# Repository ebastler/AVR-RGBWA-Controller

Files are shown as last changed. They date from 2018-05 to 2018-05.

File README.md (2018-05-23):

## AVR RGBWA Controller
### Overview
This project was born as an ambient light for a living room. I wanted five controllable LED channels and compatibility with 12 V or 24 V LED stripes and an easy to use interface with a single rotary encoder (and it's push button). As a controller I chose an "Arduino pro Micro" from China, because I wanted to be able to add USB support later on and the arduino features an ATmega32U4 with all necessary external components. It was, however, programmed entirely in C without any Arduino-headers or library.

### Schematic and Layout
I tried to only use cheap and easily available standard components, all of which should be available at my usual component shop, Reichelt.de.
While the Layout was made using almost entirely SMD components, all footprints are large enough to be easily soldered by hand without SMD soldering experience or expensive equipment.
The double sided layout itself needed a fair amount of VIAs, but it should be possible to manufacture it at home with a bit of experience in making PCBs.

Eagle files, Gerber Files and pdf layouts, as well as pngs of both layers and the schematic can be found in the PCB folder.

The Arduino can be directly soldered onto the PCB using pin headers and programmed with a 6pin ISP port

### Code
The code is written in plain C, without relying on any non-standard libraries. I have written and compiled it with the most recent version of Atmel Studio, which handles most standard library includes and compiler options by itself, so I will only upload the plain .c file without a makefile apart from the compiled .hex.

I am using the [rotary encoder example of Peter Dannegger](https://www.mikrocontroller.net/articles/Drehgeber "microcontroller.net"). I slightly adapted it to my needs, but left it mostly unchanged.

The push-button as well as the rotary encoder are software-debounced and checked using interrupts.
Some values can be set in the variable definitions at the beginning of the file (initial WA value, initial RGB value, initial brightness, initial colow-sweep speed).

The LEDs are controlled using a soft PWM loop.

### Use
The controller must be fed with a voltage between 8 V and 30V DC, I would recommend using 12 V or 24 V and Common Anode LED stripes with the same operating voltage. Stripes are connected to the terminals next to the power jack. The closest terminal is the positive voltage, the others are the open drain outputs, which are supposed to be connected with the negative wire(s) of the stripes in the following order: R-G-B-W-A-X (X being an unused channel at constant 50% duty cycle in my code, brightness is applied to it as well).
It is controlled with a single rotary encoder and it's push button. A short click on the encoder cycles between the three available lighting modes.

Modes:
1. White: Rotating the encoder changes the balance between warm white and cold white (startup value being both at full power). It is possible to scroll "endlessly" - the colors will loop and no hard transition is visible.
2. RGB Manual: Rotating the encoder cycles through the RGB spectrum with a simple algorithm that never uses more than 2 colors at the same time. It is possible to scroll "endlessly" - the colors will loop and no hard transition is visible.
3. RGB Automatic: The controller automatically cycles through the RGB spectrum and behaves as if the user was constantly rotating the encoder. Operating the encoder in this mode changes the speed with which the colors fade (clockwise -> faster).
A short click in the third mode leads back to the first.

All modes can be interrupted at any point by a long click (~.5s), which will lead to the brightness control function. Here, the encoder controls the brightness which is globally applied to all channels and modes. A short click exits the brightness control and leads back to the mode that was active before.

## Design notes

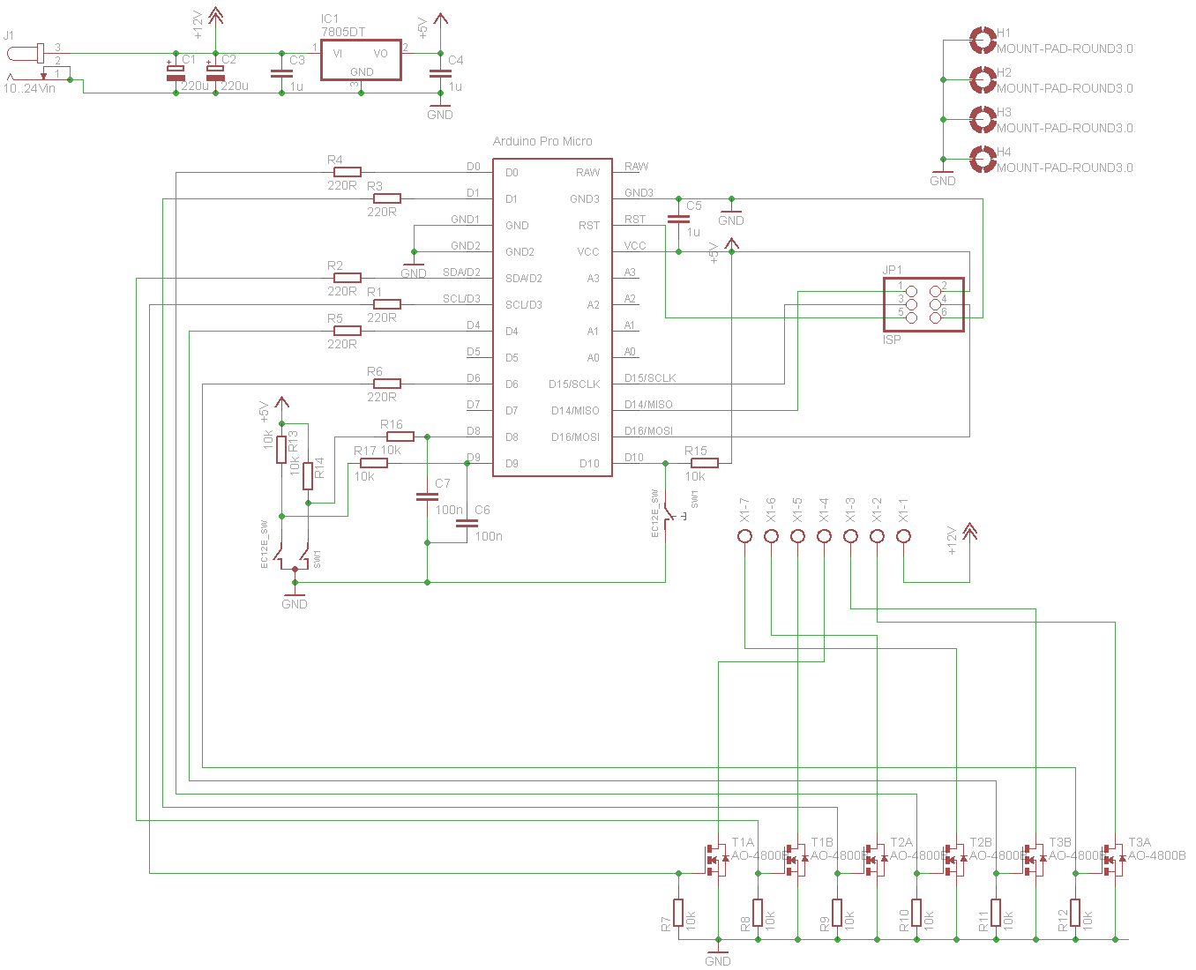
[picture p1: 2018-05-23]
PCB/rgwa_controller_schematic.png

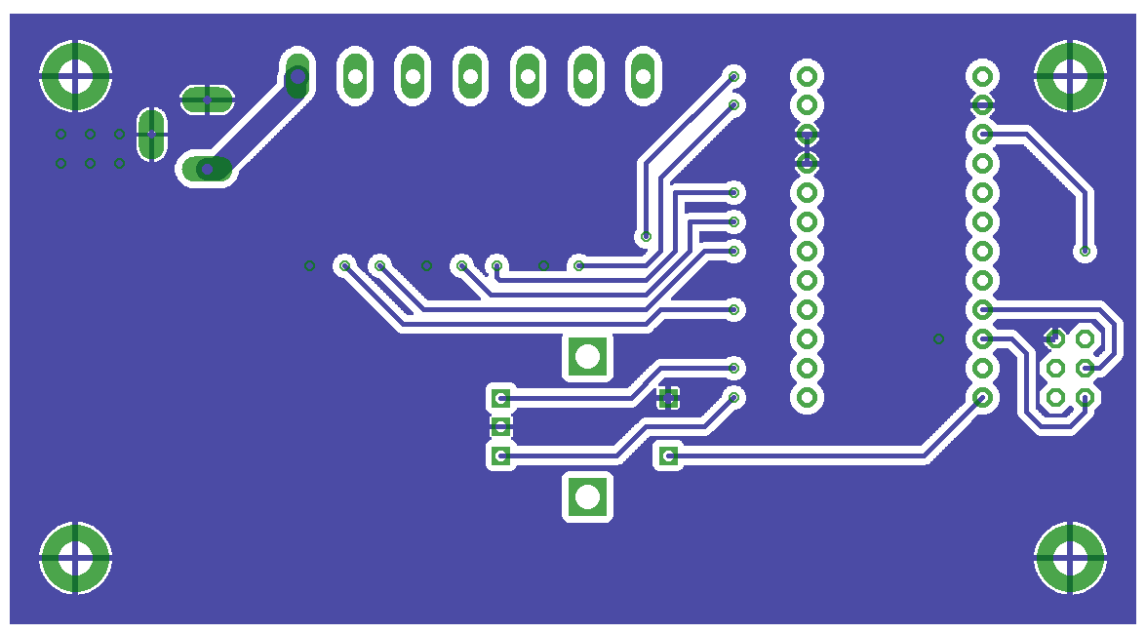
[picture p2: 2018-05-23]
PCB/rgwa_controller_pcb_bottomlayer.png

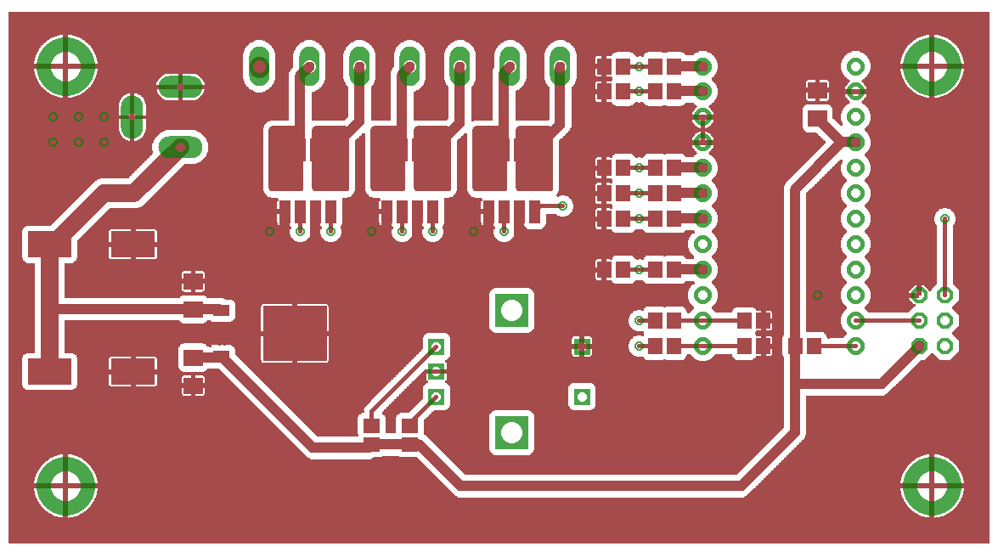
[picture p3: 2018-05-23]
PCB/rgwa_controller_pcb_toplayer.png

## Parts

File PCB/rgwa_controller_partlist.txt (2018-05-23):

Partlist

Exported from rgbwa.sch at 23/05/2018 21:52:27

EAGLE Version 7.1.0 Copyright (c) 1988-2014 CadSoft

Assembly variant: 

Part     Value              Device             Package       Library           Sheet

C1       220u               CPOL-EU150CLZ-1010 150CLZ-1010   rcl               1
C2       220u               CPOL-EU150CLZ-1010 150CLZ-1010   rcl               1
C3       1u                 C-EUC1206          C1206         rcl               1
C4       1u                 C-EUC1206          C1206         rcl               1
C5       1u                 C-EUC1206          C1206         rcl               1
C6       100n               C-EUC0805          C0805         rcl               1
C7       100n               C-EUC0805          C0805         rcl               1
IC1      7805DT             7805DT             TO252         linear            1
J1       10..24Vin          JACK-PLUG1         SPC4078       con-jack          1
JP1      ISP                PINHD-2X3          2X03          pinhead           1
R1       220R               R-EU_M0805         M0805         rcl               1
R2       220R               R-EU_M0805         M0805         rcl               1
R3       220R               R-EU_M0805         M0805         rcl               1
R4       220R               R-EU_M0805         M0805         rcl               1
R5       220R               R-EU_M0805         M0805         rcl               1
R6       220R               R-EU_M0805         M0805         rcl               1
R7       10k                R-EU_M0805         M0805         rcl               1
R8       10k                R-EU_M0805         M0805         rcl               1
R9       10k                R-EU_M0805         M0805         rcl               1
R10      10k                R-EU_M0805         M0805         rcl               1
R11      10k                R-EU_M0805         M0805         rcl               1
R12      10k                R-EU_M0805         M0805         rcl               1
R13      10k                R-EU_M0805         M0805         rcl               1
R14      10k                R-EU_M0805         M0805         rcl               1
R15      10k                R-EU_M0805         M0805         rcl               1
R16      10k                R-EU_M0805         M0805         rcl               1
R17      10k                R-EU_M0805         M0805         rcl               1
SW1      EC12E_SW           EC12E_SW           ALPS_EC12E_SW switch-alps       1
T1       AO-4800B           NMOS2SM8           SM8           zetex             1
T2       AO-4800B           NMOS2SM8           SM8           zetex             1
T3       AO-4800B           NMOS2SM8           SM8           zetex             1
U$1      PROMICRO           PROMICRO           PROMICRO      arduino pro micro 1
X1                          AK300/7            AK300/7       con-ptr500        1

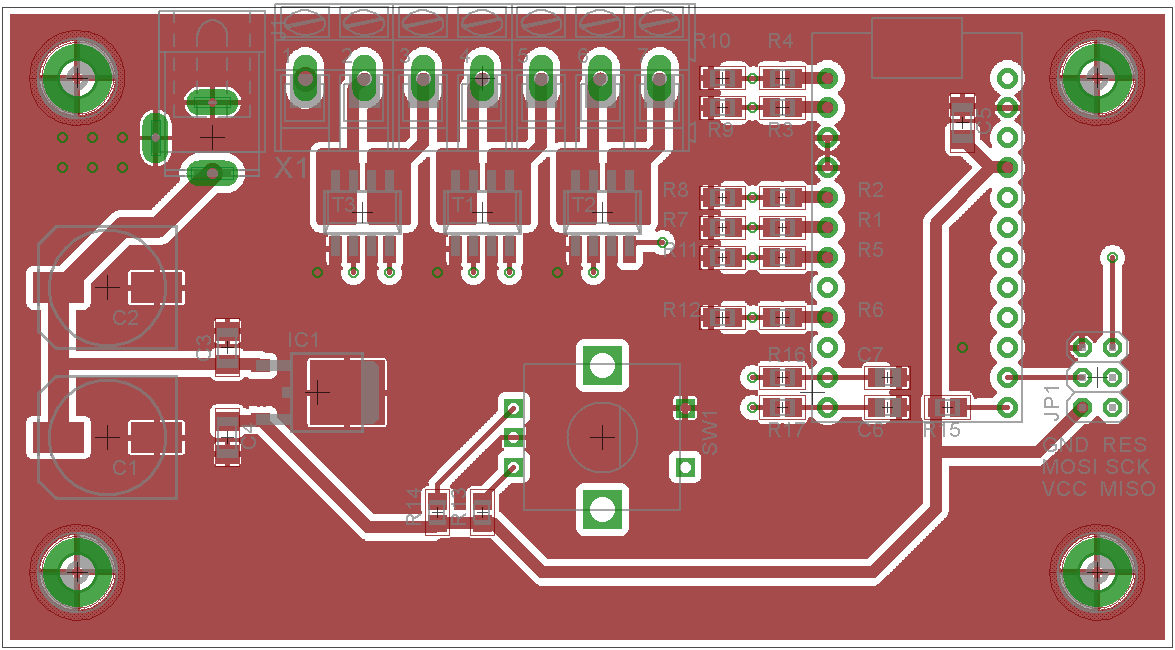
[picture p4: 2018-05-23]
PCB/rgwa_controller_pcb_toplayer_components.png

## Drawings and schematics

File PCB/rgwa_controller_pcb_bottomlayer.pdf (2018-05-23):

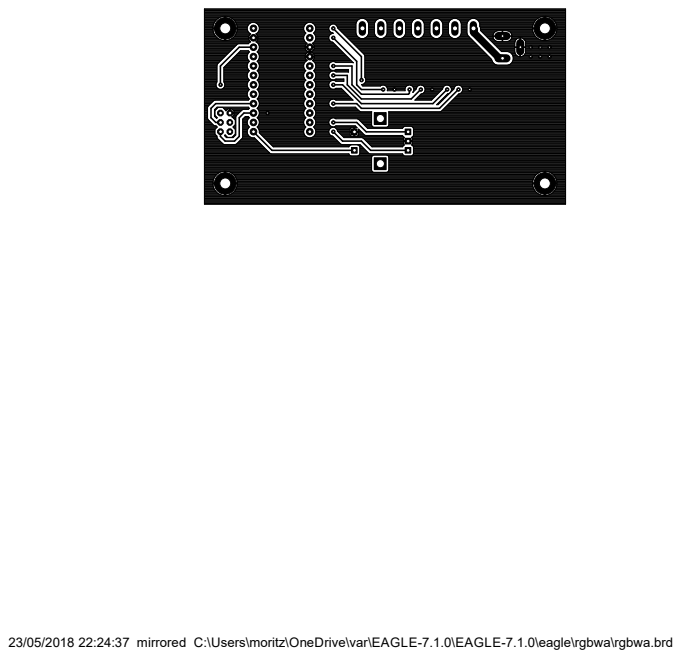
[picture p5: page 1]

23/05/2018 22:24:37 mirrored C:\Users\moritz\OneDrive\var\EAGLE-7.1.0\EAGLE-7.1.0\eagle\rgbwa\rgbwa.brd

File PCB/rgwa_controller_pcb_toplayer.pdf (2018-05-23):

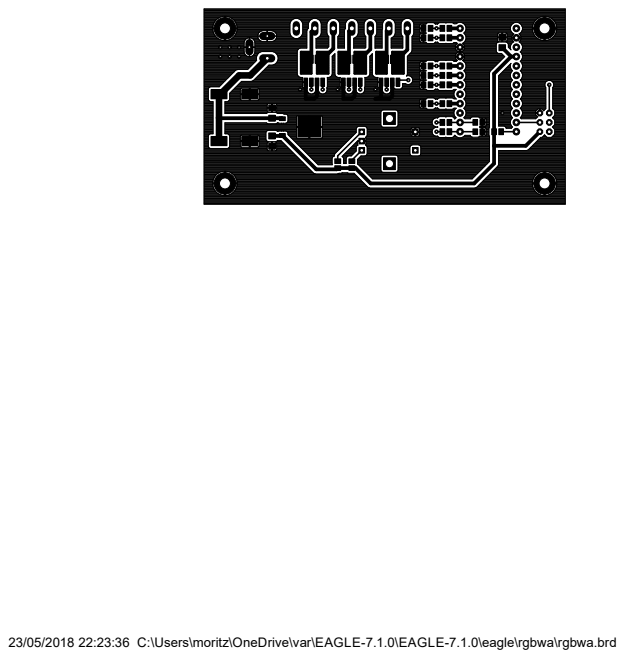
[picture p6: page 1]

23/05/2018 22:23:36 C:\Users\moritz\OneDrive\var\EAGLE-7.1.0\EAGLE-7.1.0\eagle\rgbwa\rgbwa.brd

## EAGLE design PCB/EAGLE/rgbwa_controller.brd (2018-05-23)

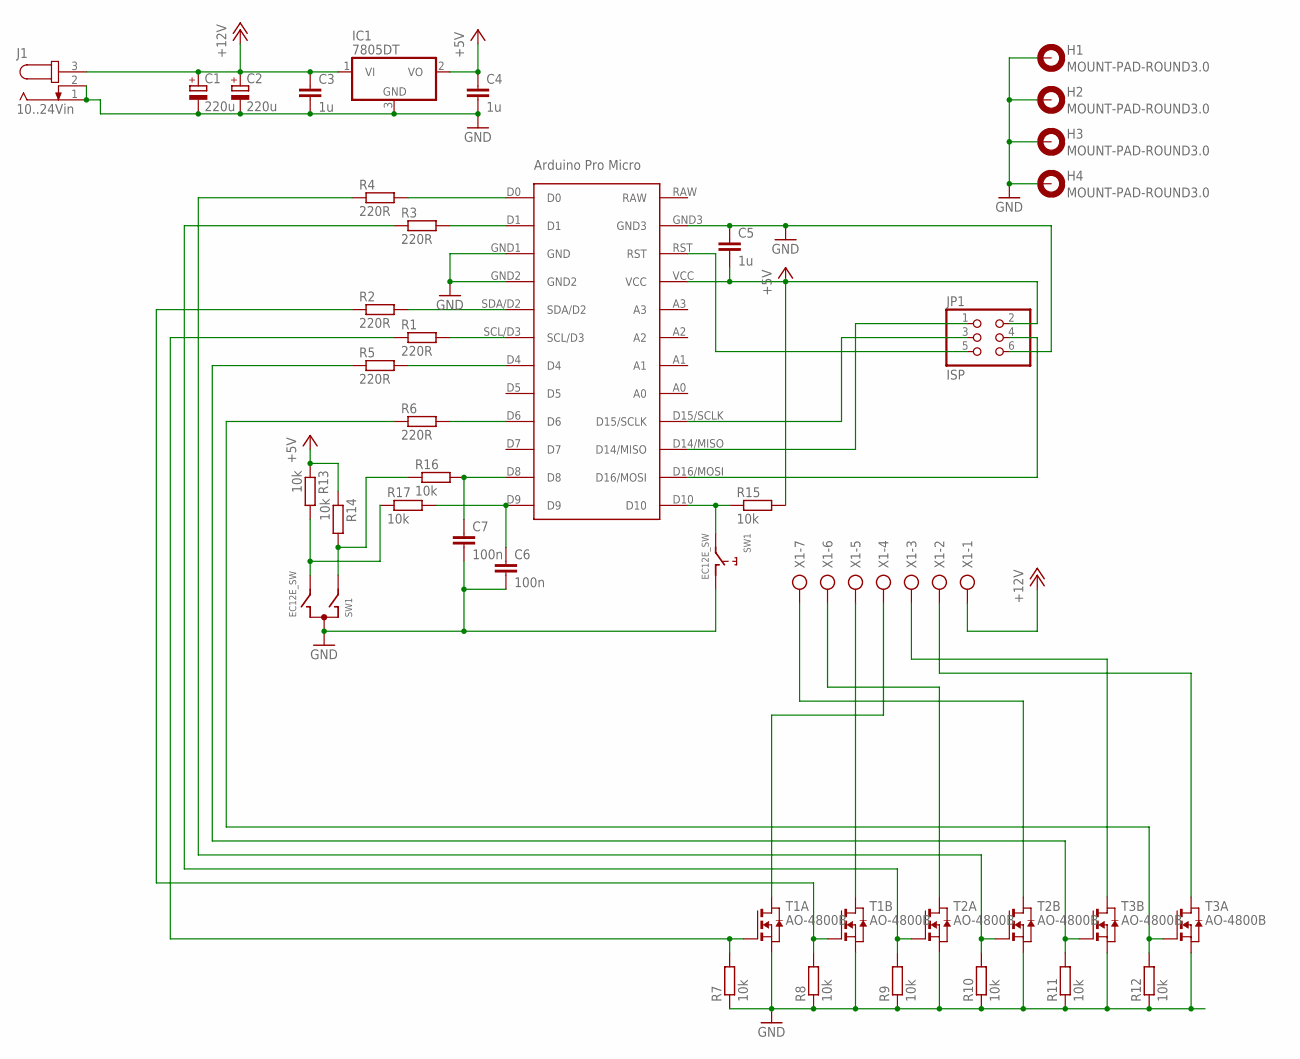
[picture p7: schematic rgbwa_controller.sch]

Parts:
C1, C2: 220u; 150CLZ-1010
C3, C4, C5: 1u; C1206
C6, C7: 100n; C0805
H1, H2, H3, H4: MOUNT-PAD-ROUND3.0; 3,0-PAD
IC1: 7805DT; TO252
J1: 10..24Vin; SPC4078
JP1: ISP; 2X03
R1, R2, R3, R4, R5, R6: 220R; M0805
R7, R8, R9, R10, R11, R12, R13, R14, R15, R16, R17: 10k; M0805
SW1: EC12E_SW; ALPS_EC12E_SW
T1, T2, T3: AO-4800B; SM8
U$1: PROMICRO
X1: AK300/7

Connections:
+5V: C4.1, C5.2, IC1.2 (VO), JP1.2, R13.1, R14.1, R15.2, U$1.VCC
+12V: C1.+, C2.+, C3.1, IC1.1 (VI), J1.3, X1.1
GND: C1.-, C2.-, C3.2, C4.2, C5.1, C6.2, C7.2, H1.B3,0, H2.B3,0, H3.B3,0, H4.B3,0, IC1.3 (GND), J1.1, J1.2, JP1.6, R7.1, R8.1, R9.1, R10.1, R11.1, R12.1, SW1.C, SW1.D (1), T1.1 (S), T1.3 (S), T2.1 (S), T2.3 (S), T3.1 (S), T3.3 (S), U$1.GND1 (GND), U$1.GND2, U$1.GND3
unnamed: R4.2, U$1.D0
unnamed: R3.2, U$1.D1
unnamed: R2.2, U$1.SDA/D2
unnamed: R1.2, U$1.SCL/D3
unnamed: R5.2, U$1.D4
unnamed: R6.2, U$1.D6
unnamed: R1.1, R7.2, T1.2 (G)
unnamed: R2.1, R8.2, T1.4 (G)
unnamed: R3.1, R9.2, T2.2 (G)
unnamed: R4.1, R10.2, T2.4 (G)
unnamed: R5.1, R11.2, T3.4 (G)
unnamed: R6.1, R12.2, T3.2 (G)
unnamed: R13.2, R17.1, SW1.B
unnamed: JP1.1, U$1.D14/MISO
unnamed: T3.7 (D), T3.8 (D), X1.2
unnamed: T1.5 (D), T1.6 (D), X1.5
unnamed: T1.7 (D), T1.8 (D), X1.4
unnamed: R14.2, R16.1, SW1.A
unnamed: JP1.3, U$1.D15/SCLK
unnamed: C6.1, R17.2, U$1.D9
unnamed: R15.1, SW1.E (2), U$1.D10
unnamed: C7.1, R16.2, U$1.D8
unnamed: JP1.5, U$1.RST
unnamed: T3.5 (D), T3.6 (D), X1.3
unnamed: T2.5 (D), T2.6 (D), X1.7
unnamed: T2.7 (D), T2.8 (D), X1.6
unnamed: JP1.4, U$1.D16/MOSI

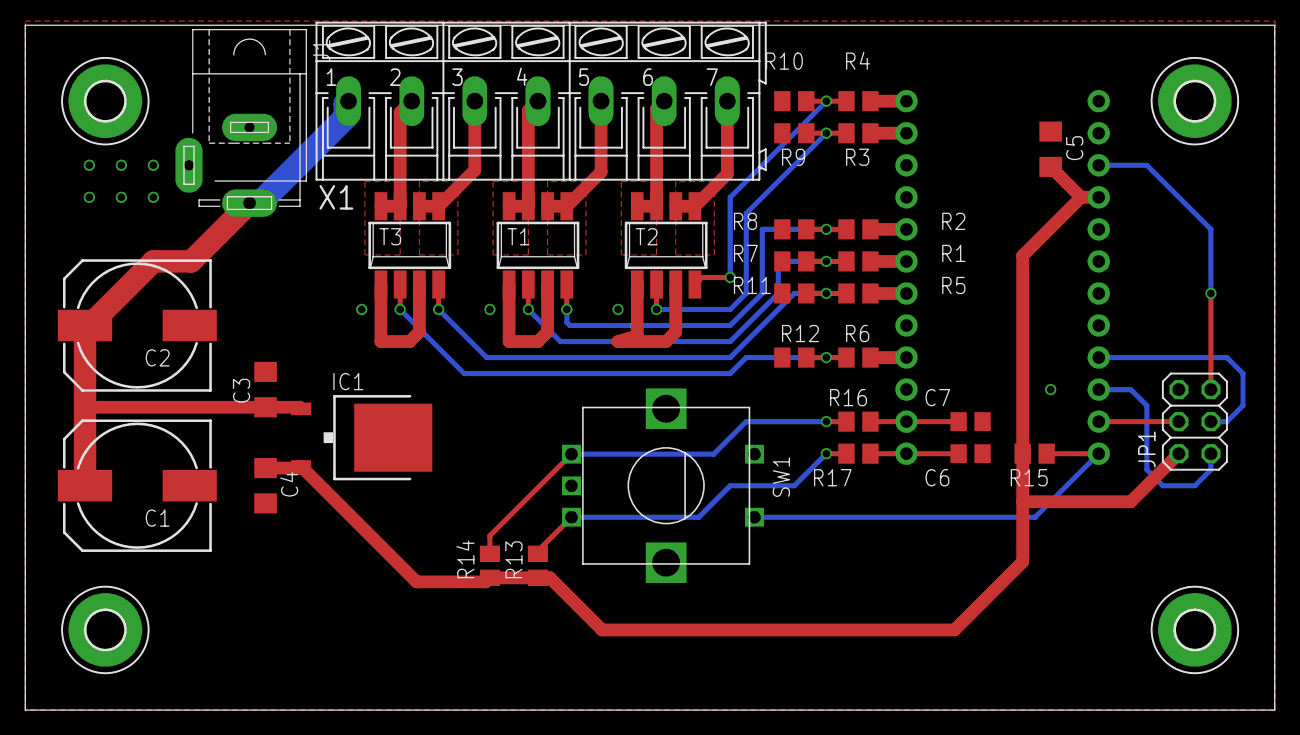
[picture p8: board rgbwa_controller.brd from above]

Board: 2 copper layers, 99.0 x 54.3 mm, 37 parts (0 on the bottom side), 30 nets.

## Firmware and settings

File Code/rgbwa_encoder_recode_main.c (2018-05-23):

/*
 * rgbwa_encoder_recode.c
 *
 * Created: 18/05/2018 23:59:35
 * Author : Moritz Plattner
 * Purpose: A simple RGB, warm- and cold-white LED stripe controller
 *          Up to 6 channels, soft-PWM, use via rotary encoder with a button
 *
 * The code for the rotary encoder was originally written 
 * by Peter Danegger: https://www.mikrocontroller.net/articles/Drehgeber
 * I used his example with little to no modification.
 * My code is written for a Atmega32u4 with a 16MHz clock. Adaptions might be
 * needed for other MCUs or clocks.
 */

// Include header files
#include <avr/io.h>
#include <avr/interrupt.h>
#include <avr/pgmspace.h>
#include <stdint.h>

// Define in/outputs for better readability
#define enc1		PB4									// Encoder pin 1
#define enc2		PB5									// Encoder pin 2
#define button		PB6									// Button input
#define LED_B		PD0									// Blue
#define LED_W		PD1									// White
#define LED_A		PD2									// Amber
#define LED_X		PD3									// Not used
#define LED_G		PD4									// Green
#define LED_R		PD7									// Red

#define XTAL        16e6								// 16MHz
#define PHASE_A     (PINB & 1<<enc1)
#define PHASE_B     (PINB & 1<<enc2)

volatile int8_t enc_delta;
volatile int8_t taster_delta = 0;

// Table of allowed encoder states used to eliminate bouncing/errors while reading the encoder
const int8_t table[16] PROGMEM = {0,0,-1,0,0,0,0,1,1,0,0,0,0,-1,0,0};
	
// Variables for the individual LED brightnesses
uint8_t R = 0;
uint8_t G = 0;
uint8_t B = 0;
uint8_t W = 0;
uint8_t A = 0;
uint8_t X = 127;									// The unused color is set to ~50% duty cycle to get a 
													// trigger signal if checking the outputs with a scope

uint8_t brightness = 127;							// initial value of the brightness (0 = min, 127= max)
uint16_t color = 0;									// initial value of the RGB color
uint8_t speed = 30;									// initial value of how fast the colors change (higher -> slower)
uint16_t white = 255;								// Initial value of the white color (0 = W, 255 = both max, 511 = A)

uint8_t key_counter;								// Variable used to count how long the button has been pressed
uint8_t key_short;
uint8_t key_long;

ISR(TIMER0_COMPA_vect)								// On timer event A check current encoder state
{
	static int8_t enc_last=0;						// Store previous value

	enc_last = (enc_last << 2)  & 0x0F;
	if (PHASE_A) enc_last |=2;
	if (PHASE_B) enc_last |=1;
	enc_delta = pgm_read_byte(&table[enc_last]);	// +1 if rotated CW, -1 if rotated CCW
	
}

ISR(TIMER0_COMPB_vect)
{
	uint8_t input = PINB & (1 << button);			// Read the button
	
	if (key_counter > 200)							// Check for a long key press
	{
		key_long = 1;								// If so, set the variable and reset the counter
		key_counter = 0;
	}
	
	if (!input)										// If the button is pressed
	{
		key_counter++;								// Raise the counter by one
		if (key_counter > 250)						// And keep it from overflowing
		{
			key_counter = 249;
		}
	}
	else if (key_counter > 3)						// If no button is pressed anymore, but the counter is >3
	{
		key_short = 1;								// Register a short keypress (registered on release)
		key_counter = 0;
	}
	else 
	{
		key_counter = 0;
	}
}

void reg_init(void)									// Initialize registers
{
	DDRD |= ( (1 << LED_R) | (1 << LED_G) | (1 << LED_B) | (1 << LED_W) | (1 << LED_A) | (1 << LED_X));		// Set LED pins as outputs
	PORTB |= ( (1 << enc1) | (1 << enc2) | (1 << button));													// Set Pullups for all inputs
	TCCR0A |= (1<<WGM01);								// CTC
	TCCR0B |= ((1<<CS01) | (1<<CS00));					// XTAL /64
	OCR0A = (uint8_t)(XTAL / 64.0 * 1e-3 - 0.5);
	OCR0B = (uint8_t)(XTAL / 64.0 * 1e-4 - 0.5);
	TIMSK0 |= ((1<<OCIE0A) | (1<<OCIE0B));
	sei();												// allow interrupts
}

int8_t encode_read(void)							// Read current state change of the rotary encoder
{
	int8_t val;
	cli();											// Disable interrupts
	val = enc_delta;
	enc_delta = 0;
	sei();
	return val;										// Allow Interrupts again
}

int8_t get_key_short(void)							// Check for a short key press
{
	uint8_t result;
	cli();
	result = key_short;
	key_short = 0;
	sei();
	return result;
}

int8_t get_key_long(void)							// Check for a long key press
{
	uint8_t result;
	cli();
	result = key_long;
	key_long = 0;
	sei();
	return result;
}

void int_to_rgb(void)								// It is pretty simple and a lot of work to explain, so no comments here
{
	if (color < 256)
	{
		R = 255;
		G = 0 + color;
		B = 0;
	}
	else if (color < 512)
	{
		R = 255 - (color - 256);
		G = 255;
		B = 0;
	}
	else if (color < 768)
	{
		R = 0;
		G = 255;
		B = 0 + (color - 512);
	}
	else if (color < 1024)
	{
		R = 0;
		G = 255 - (color - 768);
		B = 255;
	}
	else if (color <  1280)
	{
		R = 0 + (color - 1024);
		G = 0;
		B = 255;
	}
	else if (color <  1536)
	{
		R = 255;
		G = 0;
		B = 255 - (color - 1280);
	}
	else if (color < 2000)
	{
		color = 0;									// If the value reaches 1536 the variable will be reset to 0.
	}
	else
	{
		color = 1535;								// If the value reaches >2000 (underflow from 0) it is set to 1535
	}												// This way you can color cycle both directions and are reset to the correct point after a over/underflow
}

void int_to_wa(void)								// Same as int_to_rgb(), just with one less LED
{
	if (white < 256)
	{
		W = 255;
		A = 0 + white;
	}
	else if (white < 512)
	{
		W = 255 - (white - 256);
		A = 255;
	}
	else if (white < 768)
	{
		W = 0 + (white - 512);
		A = 255;
	}
	else if (white < 1024)
	{
		W = 255;
		A = 255 - (white - 768);
	}
	else if (white < 2000)
	{
		white = 0;
	}
	else
	{
		white = 1023;
	}
}

void softPWM(void)									// Software PWM for the LEDs
{	
	uint8_t R_out = R*brightness/127;				// Apply multiplicative brightness to all LEDs
	uint8_t G_out = G*brightness/127;
	uint8_t B_out = B*brightness/127;
	uint8_t W_out = W*brightness/127;
	uint8_t A_out = A*brightness/127;
	uint8_t X_out = X*brightness/127;
	if (R_out != 0) PORTD |= ( 1 << LED_R);			// Enable the LEDs only if their brightness values are > 0, so that they stay black if their values are 0
	if (G_out != 0) PORTD |= ( 1 << LED_G);
	if (B_out != 0) PORTD |= ( 1 << LED_B);
	if (W_out != 0) PORTD |= ( 1 << LED_W);
	if (A_out != 0) PORTD |= ( 1 << LED_A);
	if (X_out != 0) PORTD |= ( 1 << LED_X);
	for(uint8_t i=0;i<255;++i)						// Soft-PWM-loop
	{
		if(i>=R_out)	PORTD &= ~(1 << LED_R);		// Disable red
		if(i>=G_out)	PORTD &= ~(1 << LED_G);		// Disable green
		if(i>=B_out)	PORTD &= ~(1 << LED_B);		// ...
		if(i>=W_out)	PORTD &= ~(1 << LED_W);
		if(i>=A_out)	PORTD &= ~(1 << LED_A);
		if(i>=X_out)	PORTD &= ~(1 << LED_X);
	}
}

void change_brightness(void)						// Change the brightness of all LEDs
{
	while (!get_key_short())
	{
		brightness += 2*encode_read();
		if (brightness > (200))						// If a underflow happened, reset it to 0
		{
			brightness = 0;
		}
		else if (brightness > 127)					// If a overflow happened, reset it to 127
		{
			brightness = 127;
		}
		softPWM();									// In order to "preview" the brightness, the PWM loop is run here as well
	}
}

void mode_white(void)								// Change between warm and cold white manually
{
	R = 0;											// Set all RGB LEDs to 0
	B = 0;
	G = 0;
	
	while(!get_key_short())	
	{
		white +=6*encode_read();
		int_to_wa();
		softPWM();
		if (get_key_long())							// After a long key press, switch to brightness regulation
		{
			change_brightness();
		}
	}
}

void mode_rgb_man(void)								// Manually select the desired RGB color
{
	W = 0;											// Set all white LEDs to 0
	A = 0;
	while(!get_key_short())
	{
		color +=6*encode_read();
		int_to_rgb();
		softPWM();
		if (get_key_long())							// After a long key press, switch to brightness regulation
		{
			change_brightness();
		}
	}
}

void mode_rgb_sweep()								// Color "wheel" - cycles through the RGB spectrum
{
	W = 0;											// Set all white LEDs to 0
	A = 0;
	while(!get_key_short())
	{
		color += 1;
		
		for (uint8_t i=0;i<speed;++i)
		{
			speed -= 3*encode_read();				// change the velocity how fast the colors cycle
			
			if (speed < 10)							// The for loop will run with the same color between 10 and 100 times
			{
				speed = 10;
			}
			if (speed > 100)
			{
				speed = 100;
			}
			
			int_to_rgb();
			softPWM();
			if (get_key_long())						// After a long key press, switch to brightness regulation
			{
				change_brightness();
			}
		}
	}
}

int main(void)
{
	reg_init();
	while (1)
	{
		mode_white();
		mode_rgb_man();
		mode_rgb_sweep();
	}
}
